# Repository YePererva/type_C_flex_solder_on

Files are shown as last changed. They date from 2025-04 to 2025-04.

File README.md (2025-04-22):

# Type C upgrade kits

Status: Work in progress

Stage: Search for affordable prototyping facility

## About:

This repository contains developments on **_in-situ_** upgrade kits for older Micro/Mini USB ports with USB Type C. The idea is to have flex-PCB (or on very thin FR-4), where:

- USB Type port is located on top layer, accompanied by a pair of 5K1 resistors. 
- Mirrored footprint of a Micro (or Mini) USB port is situated at the bottom layer.
- Use of 0603 size of resistors would keep this project manually solderable

Theoretically, it allows for upgrading older devices by directly soldering of adapter over existing footprint. 

The Content Repository contains three variations of adapters:

- `micro_edge`
    
    prototype of micro USB replacement, where alignment is done on the PCB edge, as is typical for ports.

- `mini_edge`
    
    prototype of mini USB replacement, where alignment is done on the PCB edge, as is typical for ports. It is interesting to note that the mini USB port appears to be of a greater length than that of the type C port.

- `micro_pads`
    
    this prototype is a design for a micro USB replacement, in which is allinged relatively to the pads of micro USB port. This is applicable in instances where the presence of additional circuitry in close proximity to the port renders edge alignment unfeasible. It results in a longer outlet of the Type C port protruding from the PCB edge.  

## Some visuals

| | Micro Edge | Mini Edge | Micro Pads |
| --- | --- |  --- |  --- |
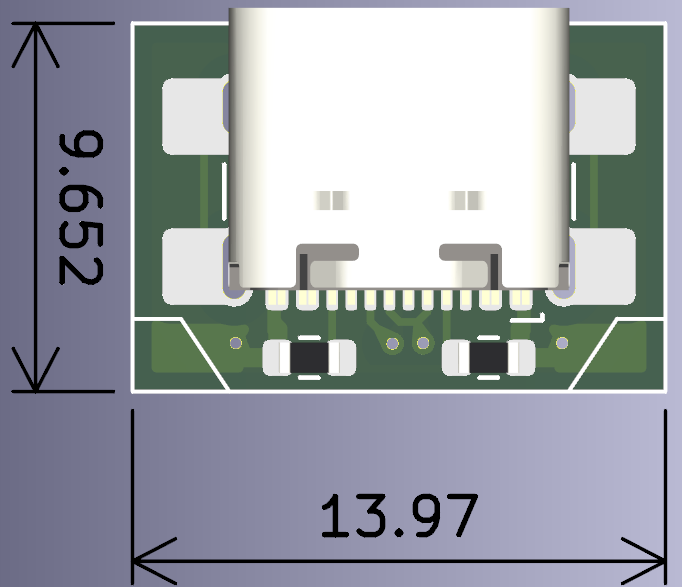
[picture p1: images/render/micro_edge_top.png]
Micro edge top view
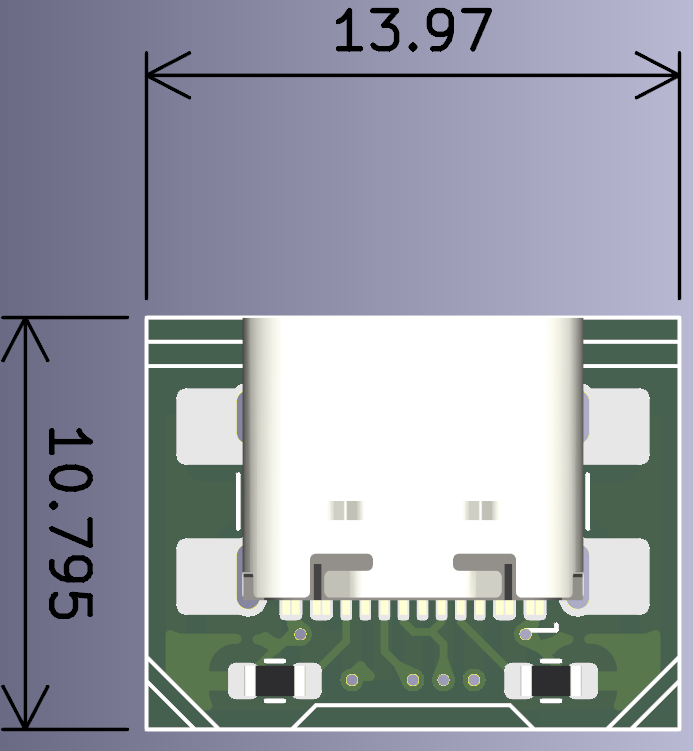
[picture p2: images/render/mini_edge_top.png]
Mini edge top view
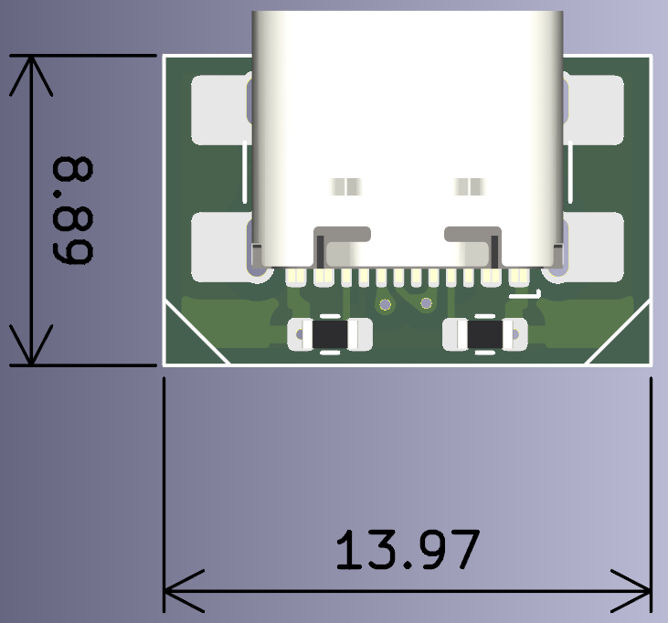
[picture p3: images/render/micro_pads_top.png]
Micro pads top view
| Top View  |   |   |   |
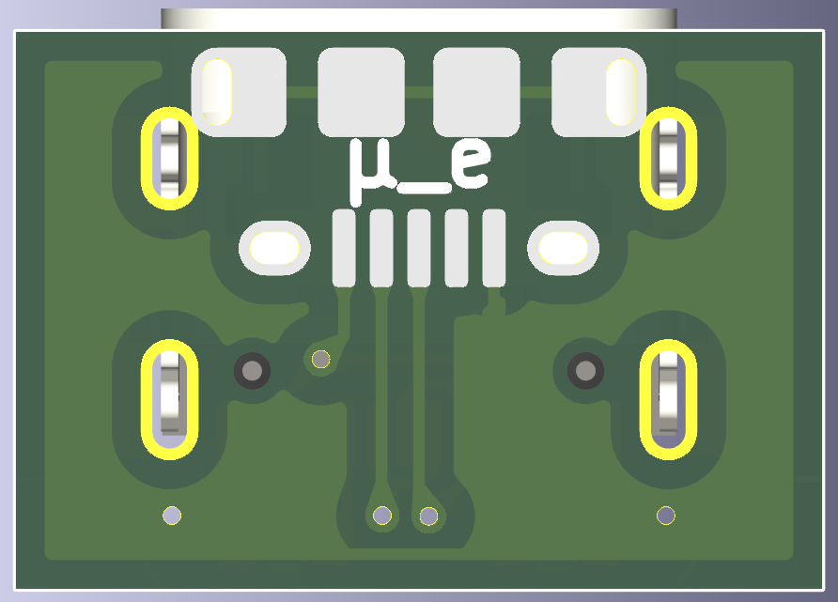
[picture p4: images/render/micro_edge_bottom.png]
Micro edge bottom view
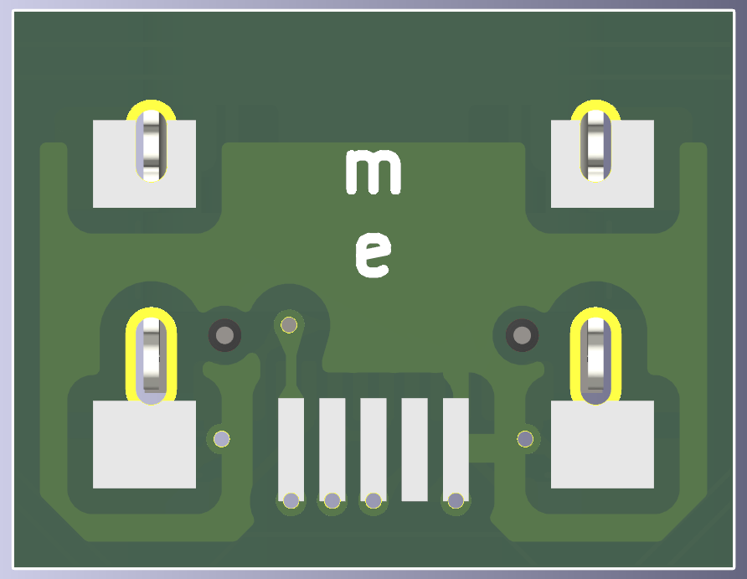
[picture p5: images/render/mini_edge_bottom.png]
Mini edge bottom view
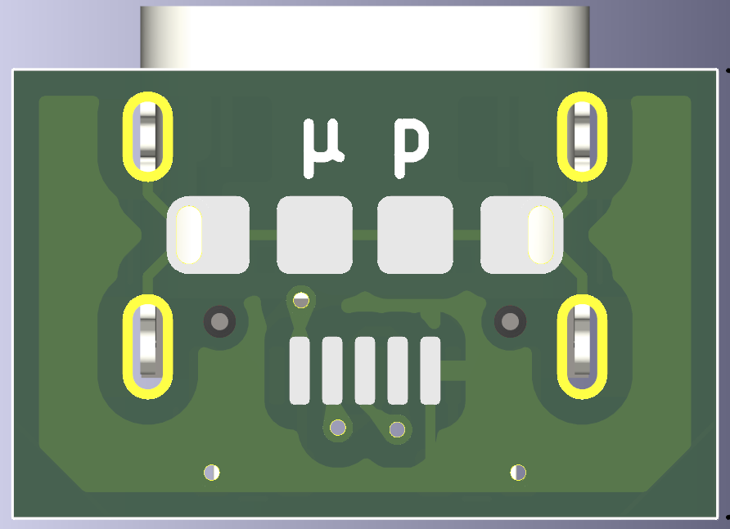
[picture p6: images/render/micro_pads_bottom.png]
Micro pads bottom view
| Bottom View  |   |   |   |

## Remarks / Thoughts / Things to test

- The utilisation of tape adhesive might be necessary for the positioning.
- Thin FR-4 might provide more rigidity than FlexPCBs
- Silkscreen has multiple perimeters. THis is for manual adjusting of form where space limitation might require it.
- For panelization of multiple designs, I found [this](https://github.com/buganini/Kikakuka) tool useful.

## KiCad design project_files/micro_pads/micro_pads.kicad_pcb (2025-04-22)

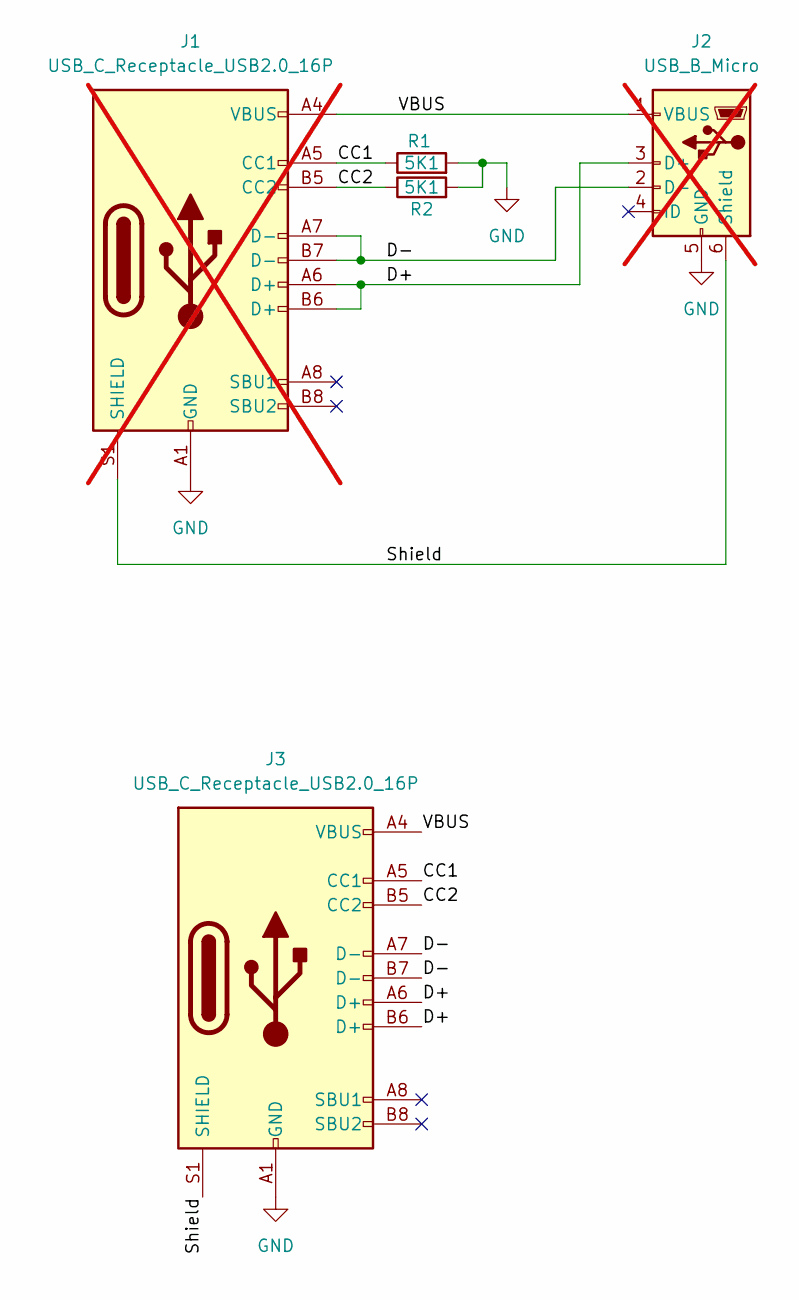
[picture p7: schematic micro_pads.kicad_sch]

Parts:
J1: USB_C_Receptacle_USB2.0_16P; USB_C_Receptacle_GCT_USB4110; not fitted
J2: USB_B_Micro; USB_Micro-B_Amphenol_10118194-0001LF_Horizontal; not fitted
J3: USB_C_Receptacle_USB2.0_16P; USB_C_Receptacle_GCT_USB4105-xx-A_16P_TopMnt_Horizontal
R1, R2: 5K1; R_0603_1608Metric

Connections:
/CC1: J1.A5 (CC1), J3.A5 (CC1), R1.1
/CC2: J1.B5 (CC2), J3.B5 (CC2), R2.1
/D+: J1.A6 (D+), J1.B6 (D+), J2.3 (D+), J3.A6 (D+), J3.B6 (D+)
/D-: J1.A7 (D-), J1.B7 (D-), J2.2 (D-), J3.A7 (D-), J3.B7 (D-)
/Shield: J1.S1 (SHIELD), J2.6 (Shield), J3.S1 (SHIELD)
/VBUS: J1.A4 (VBUS), J1.A9 (VBUS), J1.B4 (VBUS), J1.B9 (VBUS), J2.1 (VBUS), J3.A4 (VBUS), J3.A9 (VBUS), J3.B4 (VBUS), J3.B9 (VBUS)
GND: J1.A1 (GND), J1.A12 (GND), J1.B1 (GND), J1.B12 (GND), J2.5 (GND), J3.A1 (GND), J3.A12 (GND), J3.B1 (GND), J3.B12 (GND), R1.2, R2.2

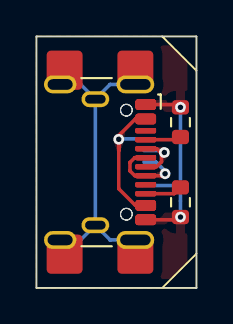
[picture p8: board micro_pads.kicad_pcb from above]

Board: 2 copper layers, 8.9 x 14.0 mm, 5 parts (1 on the bottom side), 7 nets.
